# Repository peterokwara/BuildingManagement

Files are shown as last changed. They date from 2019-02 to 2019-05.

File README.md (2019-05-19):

# Table of Contents

- [Table of Contents](#table-of-contents)
- [Building Management System](#building-management-system)
- [Video example](#video-example)
- [Dashboard](#dashboard)
- [Hardware setup](#hardware-setup)
  - [Esp & Current sensor](#esp--current-sensor)
  - [Esp & Dht sensor](#esp--dht-sensor)
  - [Esp & Motion sensor](#esp--motion-sensor)
  - [Esp & Relay](#esp--relay)
- [Installation](#installation)
  - [Esp](#esp)
  - [Raspberry Pi](#raspberry-pi)
  - [Server](#server)
  - [Client](#client)
- [Usage](#usage)
  - [Raspberry Pi](#raspberry-pi-1)
  - [Website (server and client)](#website-server-and-client)
- [Contributing](#contributing)
- [License](#license)

# Building Management System

This project seeks to demonstrate the use of MQTT protocol and MERN stack for building an IoT Building Management System for commercial usage, where parameters such as building occupancy, energy demand, andenergy consumption are measured and displayed on an online database and dashboard.

A more detailed description of the project can be found [here](https://github.com/peterokwara/BuildingManagement/blob/master/Project%20Report.pdf).

# Video example

A video of the project working (hardware)

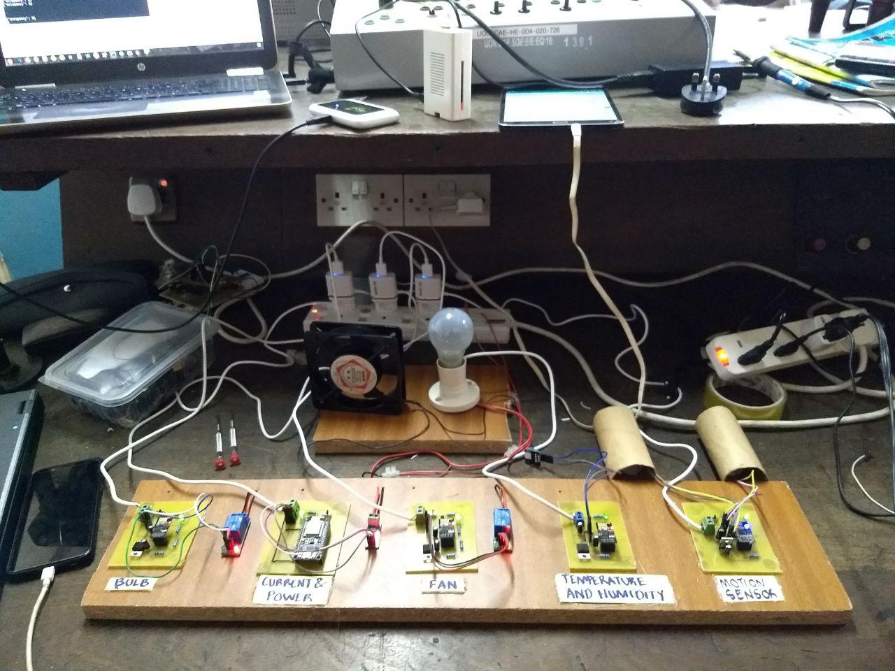
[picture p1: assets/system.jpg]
board setup of the building management system
<a href="https://www.youtube.com/watch?v=Yh3uR8R79lM" target="_blank"></a>

A video of the project working (software)

<a href="https://youtu.be/3eJK0t_gp44
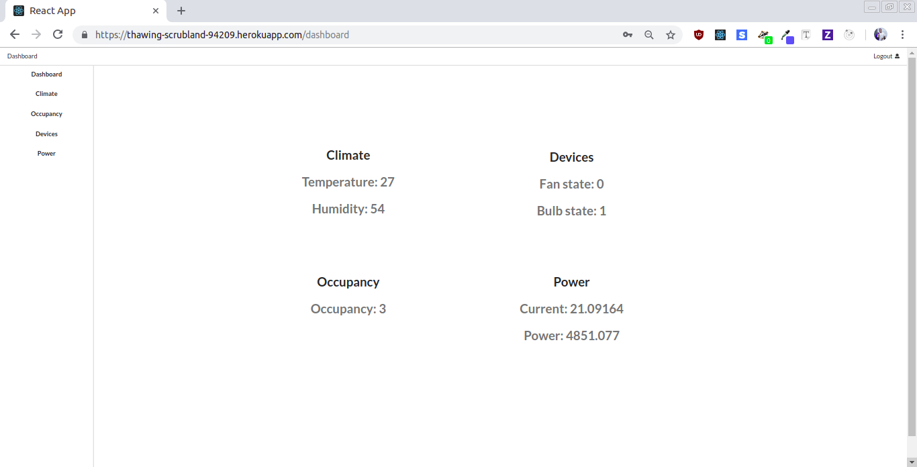
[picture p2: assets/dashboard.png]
video of the dashboard
" target="_blank"></a>

# Dashboard

You can access the dashboard after you sign up [here](https://thawing-scrubland-94209.herokuapp.com/)

# Hardware setup

## Esp & Current sensor

Circuit design

<p  align="center">
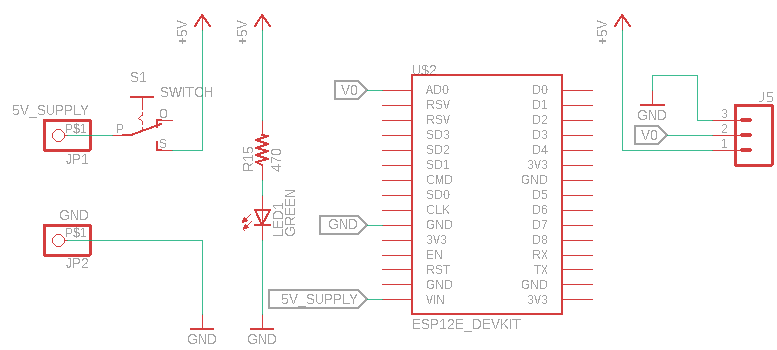
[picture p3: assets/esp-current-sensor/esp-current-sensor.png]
  
</p>

Board design and the final look

<p align="center">
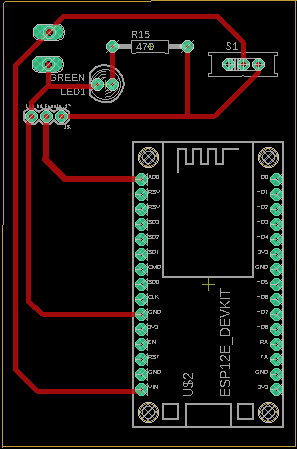
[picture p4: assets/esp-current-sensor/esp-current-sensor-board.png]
  
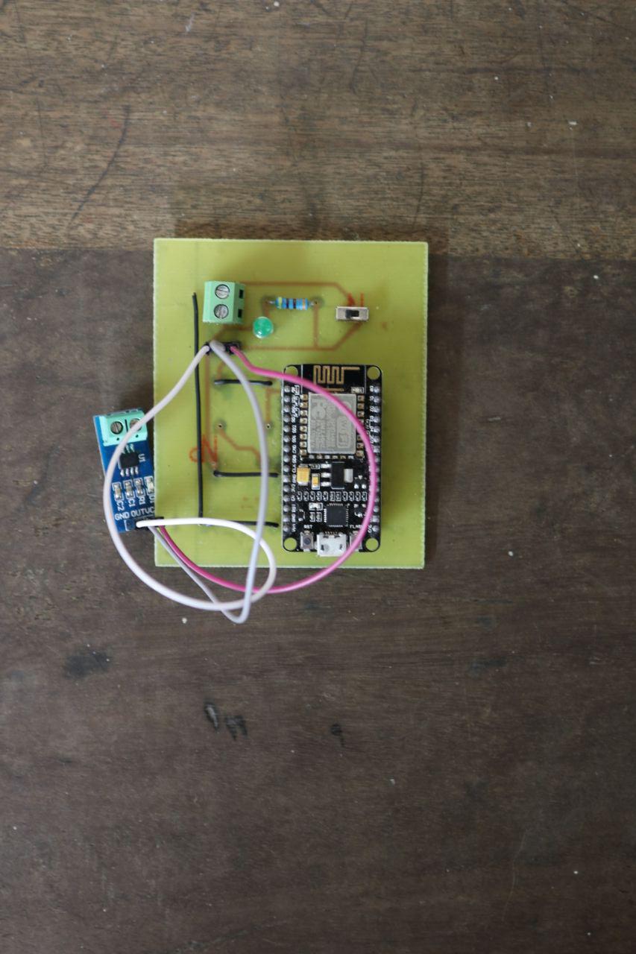
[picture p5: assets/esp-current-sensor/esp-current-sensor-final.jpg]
   
</p>

## Esp & Dht sensor

Circuit design

<p align="center">
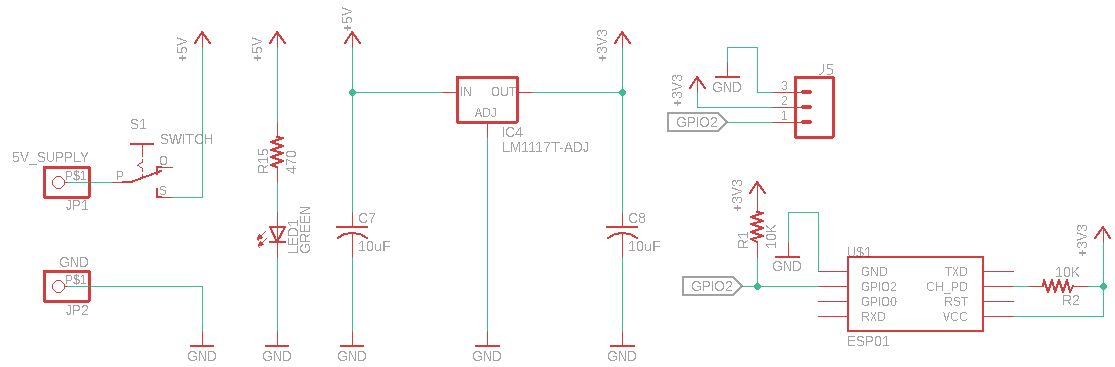
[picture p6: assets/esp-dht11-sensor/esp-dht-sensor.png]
  
</p>

Board design and the final look

<p align="center">
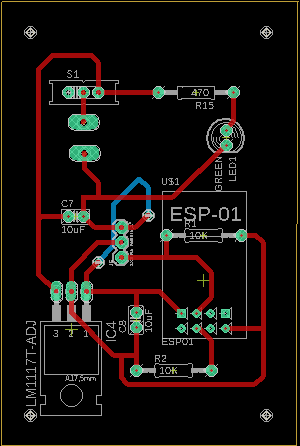
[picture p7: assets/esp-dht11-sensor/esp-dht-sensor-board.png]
  
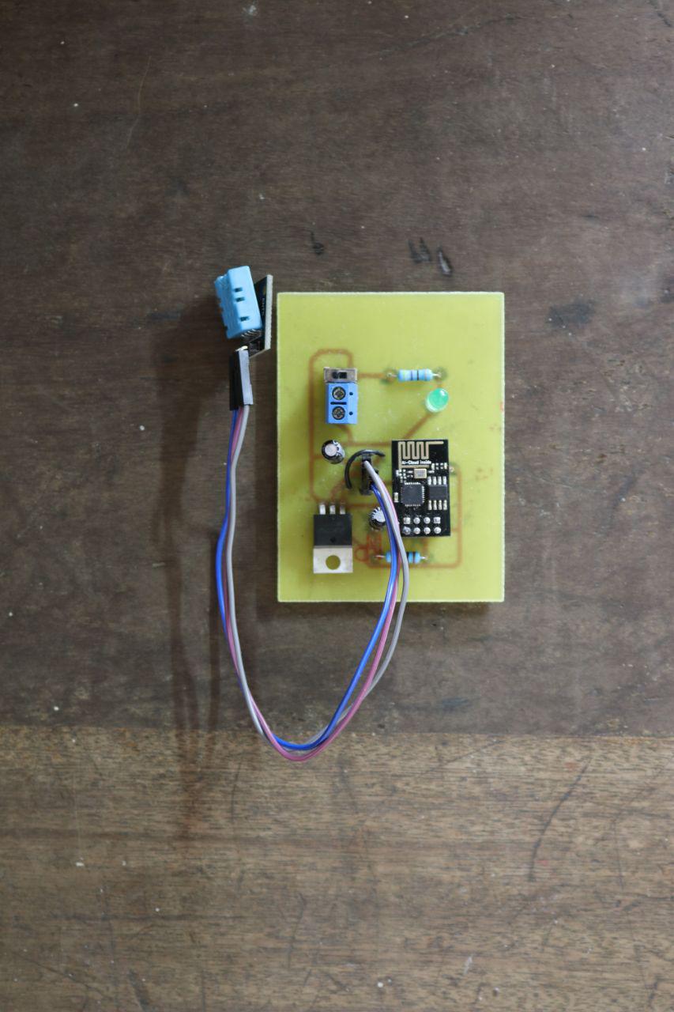
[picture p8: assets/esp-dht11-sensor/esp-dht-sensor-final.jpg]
   
</p>

## Esp & Motion sensor

Circuit design

<p align="center">
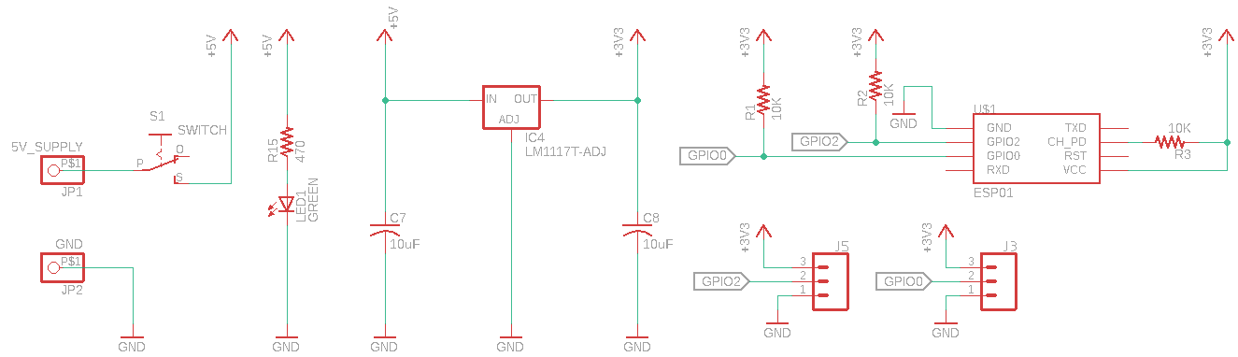
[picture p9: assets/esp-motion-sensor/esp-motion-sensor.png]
  
</p>

Board design and the final look

<p align="center">
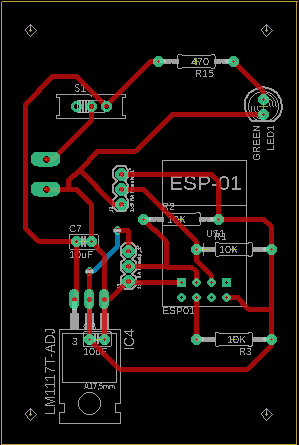
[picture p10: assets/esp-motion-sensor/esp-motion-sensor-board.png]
  
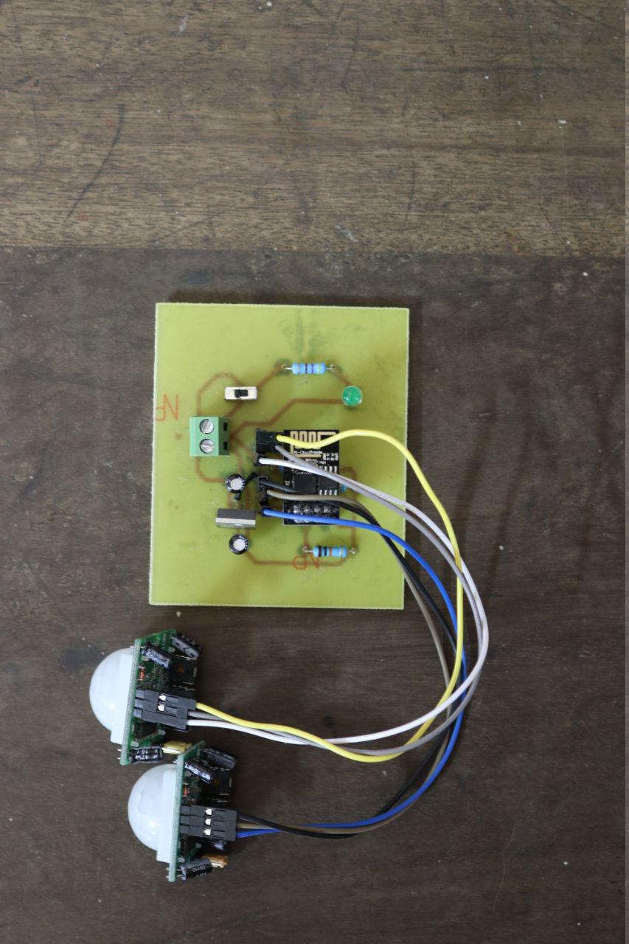
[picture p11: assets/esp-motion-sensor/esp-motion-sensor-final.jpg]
   
</p>

## Esp & Relay

Circuit design

<p align="center">
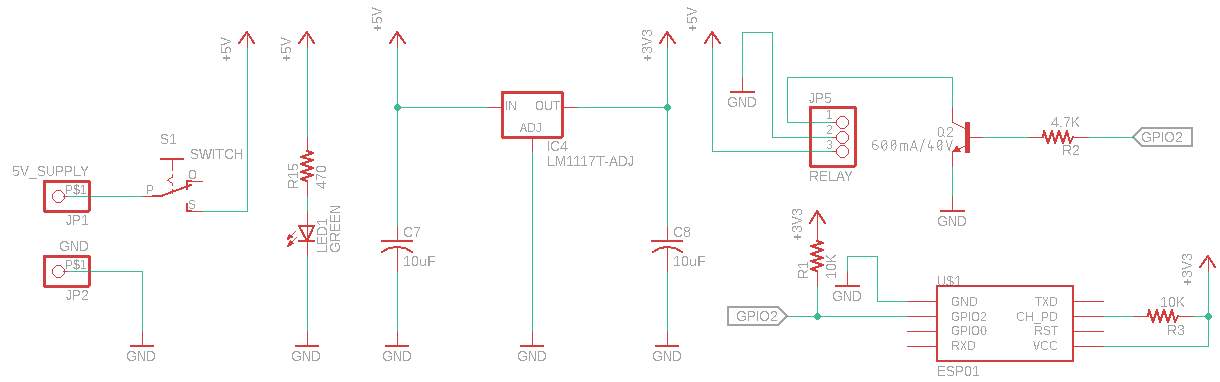
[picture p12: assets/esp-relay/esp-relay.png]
  
</p>

Board design and the final look

<p align="center">
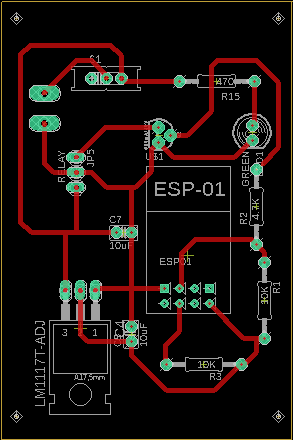
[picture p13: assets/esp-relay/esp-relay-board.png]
  
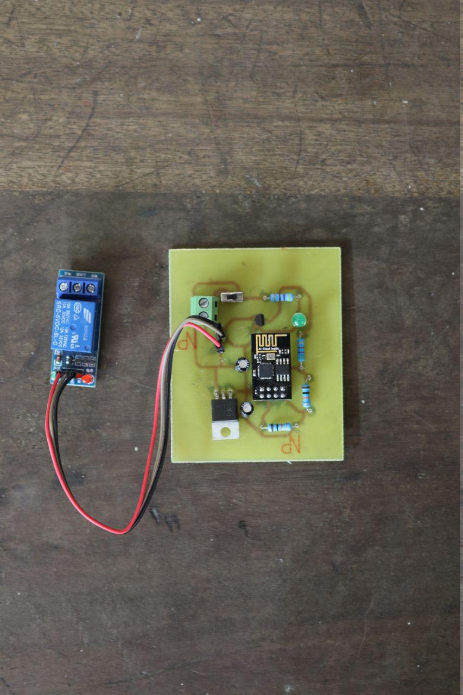
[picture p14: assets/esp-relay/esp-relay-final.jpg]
   
</p>

# Installation

## Esp

Installing in an ESP8266-01 and NodeMCU involves pushing the python files into the device whether it's via a usb to ttl or just a usb cable. This can be done using the command

```bash
sudo ampy --port /dev/ttyUSB0 --baud 115200 put main.py
sudo ampy --port /dev/ttyUSB0 --baud 115200 put config.py
sudo ampy --port /dev/ttyUSB0 --baud 115200 put connectWifi.py
```

You need to create a config.py file with the following information for each and every esp folder (current-sensor, dht-sensor, motion-sensor, relay-bulb, relay-fan)

```python
MQTT_CONFIG = {
    'SENSOR_ID': '',
    'MQTT_HOST': '',
    'PORT': '',
    'PUB_TOPIC': ''
}

WIFI_CONFIG = {
    'WIFI_ESSID': '',
    'WIFI_PASSWORD': ''
}
```

## Raspberry Pi

To install npm packages used for the Raspberry Pi, you run.

```bash
npm install axios mongoose mqtt
```

You also need to create a config folder and have two files that contain config/broker.js

```js
module.exports = {
  brokerUrl: ""
};
```

and config/server.js

```js
module.exports = {
  serverUrl: ""
};
```

## Server

To install npm packages used for the server, you run.

```bash
npm install axios bcryptjs body-parser concurrently cors express gravatar jsonwebtoken mongoose mqtt passport passport-jwt recharts validator
```

You also need to have a config/keys_dev.js with the configuration above. The mongoUri and secretOrKey are obtained when you create a mongodb on https://mlab.com the database I used.

```js
module.exports = {
  mongoUri: "",
  secretOrKey: ""
};
```

## Client

To install npm packages used for the client, you run.

```bash
npm install jwt-decode axios react-redux redux recharts redux-thunk semantic-ui-css semantic-ui-react
```

# Usage

## Raspberry Pi

To run the code for Raspberry Pi just cd into the folder and run

```bash
node app.js
```

To ensure that the Raspberry Pi runs the code whenever it boots, edit the rc.local file

```
sudo nano /etc/rc.local
```

and add

```
node app.js &
```

## Website (server and client)

To run a local development of the website, all you need to do is to do the installation setup then once that is done

```
cd site && npm run dev
```

# Contributing

Pull requests are welcome. For major changes, please open an issue first to discuss what you would like to change.

Please make sure to update tests as appropriate.

# License

[MIT](https://github.com/peterokwara/BuildingManagement/blob/master/LICENSE)

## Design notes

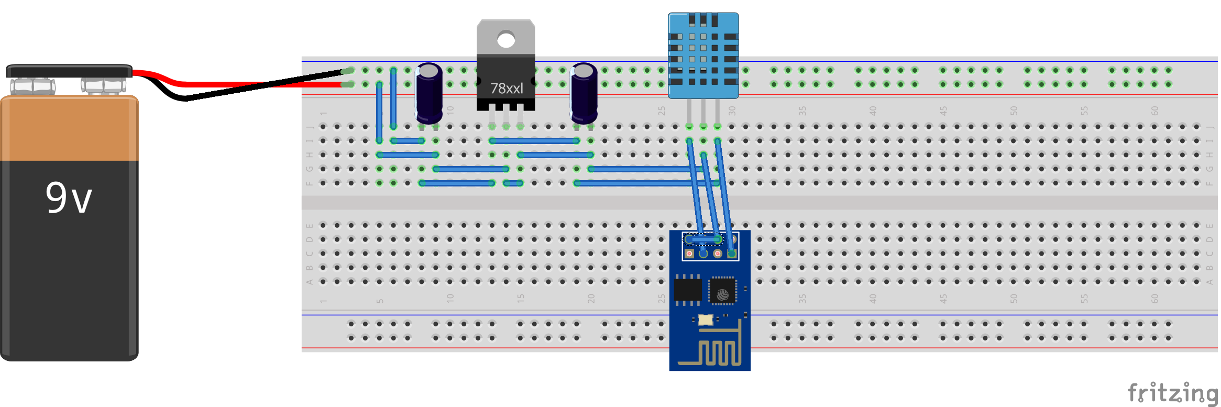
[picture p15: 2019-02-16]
schematics/Fritzing/esp_and_temp_sensor/esp_temp_sensor_bb.png

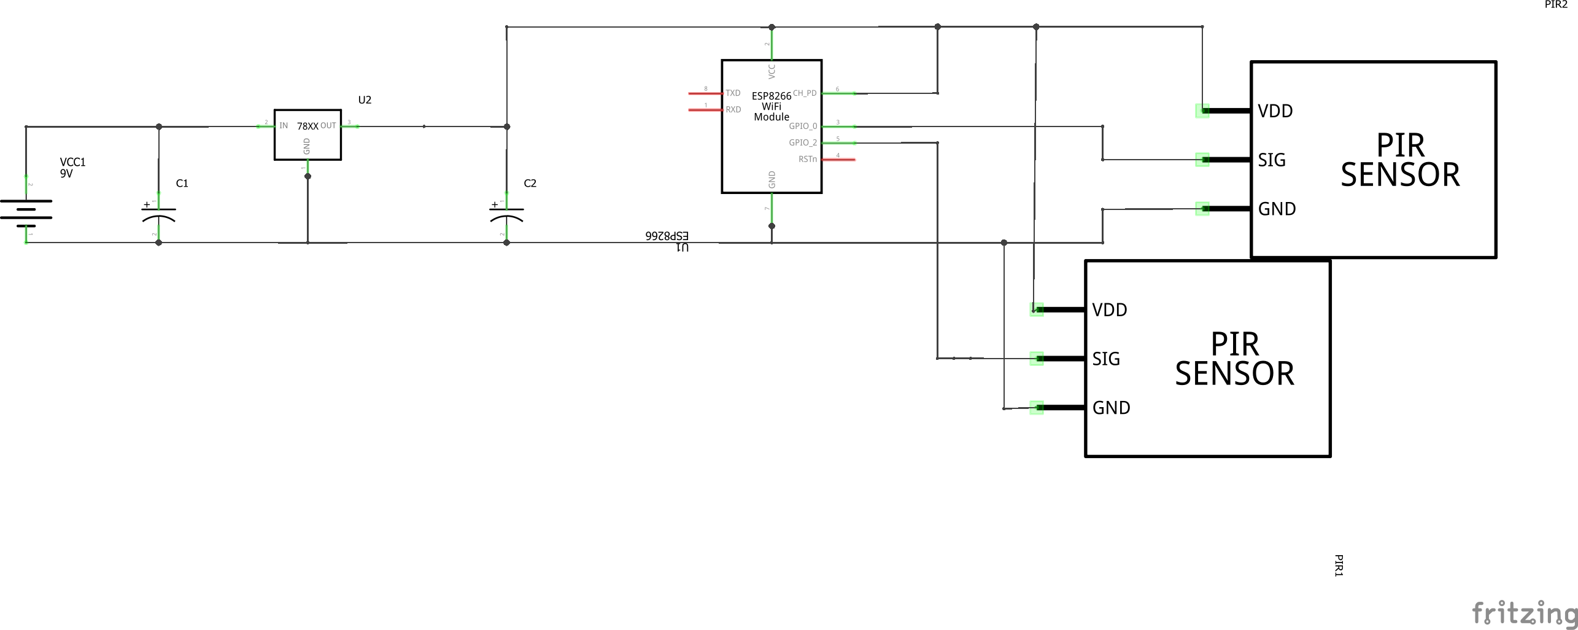
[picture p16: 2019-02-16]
schematics/Fritzing/esp_and_motion_sensor/esp_motion_sensor_schem.png

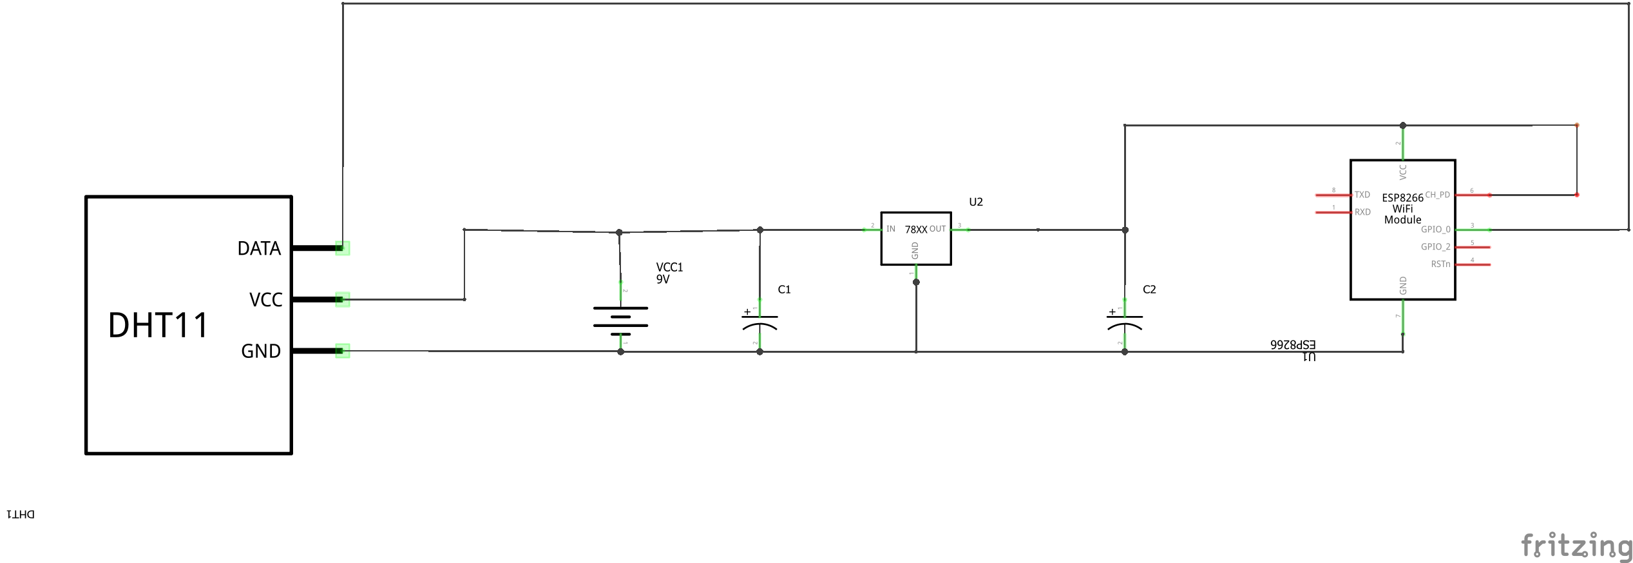
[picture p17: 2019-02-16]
schematics/Fritzing/esp_and_temp_sensor/esp_temp_sensor_schem.png

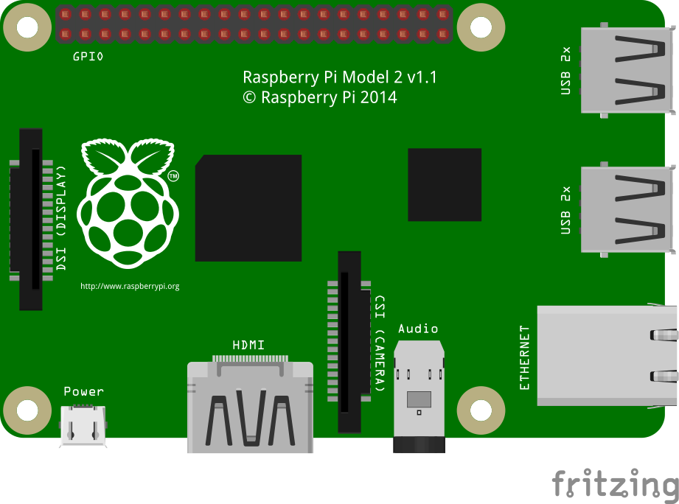
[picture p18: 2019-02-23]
schematics/Fritzing/raspberry_pi/raspberry_pi_bb.png

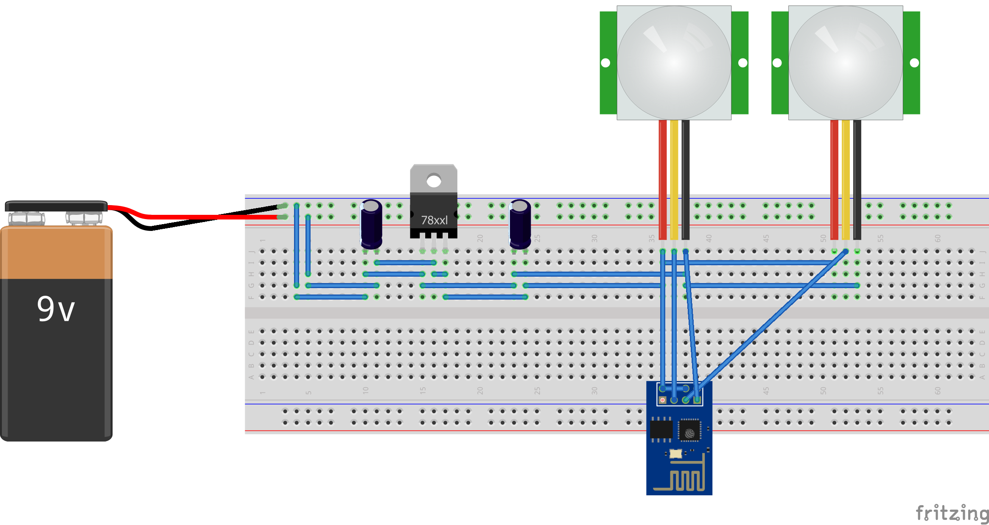
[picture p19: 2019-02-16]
schematics/Fritzing/esp_and_motion_sensor/esp_motion_sensor_bb.png

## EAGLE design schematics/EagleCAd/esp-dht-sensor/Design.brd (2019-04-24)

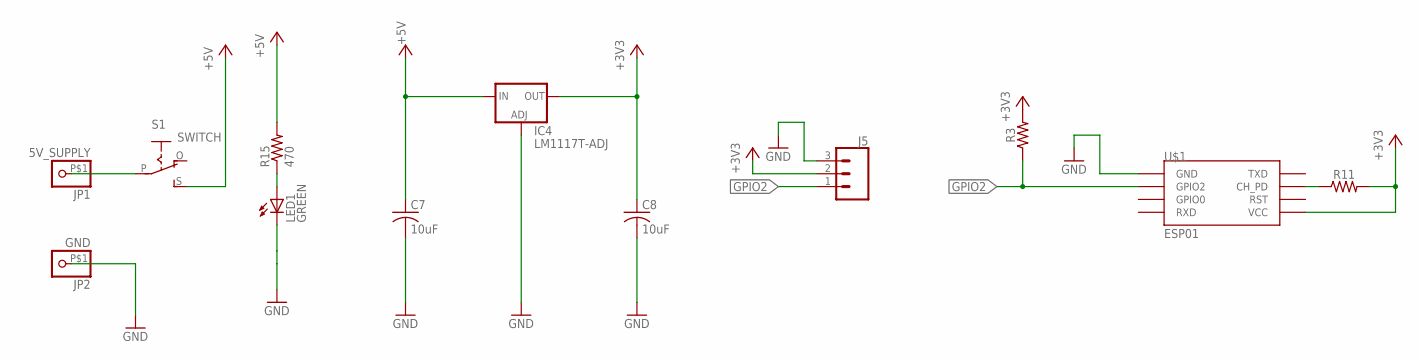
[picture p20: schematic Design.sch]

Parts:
C7, C8: 10uF; C025-025X050
IC4: LM1117T-ADJ; TO220
J5: 1x3 RA Female .1"; 1X03
JP1: 5V_SUPPLY; 1X1-BIGPOGO
JP2: GND; 1X1-BIGPOGO
LED1: GREEN; LED5MM
R3, R11: 10k; 0207/12
R15: 470; 0207/12
S1: SWITCH; EG1218
U$1: ESP01

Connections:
+3V3: C8.1, IC4.2 (OUT), J5.2, R3.2, R11.2, U$1.VCC
+5V: C7.1, IC4.3 (IN), R15.2, S1.S
GND: C7.2, C8.2, IC4.1 (ADJ), J5.3, JP2.P$1, LED1.K (C), U$1.GND
GPIO2: J5.1, R3.1, U$1.GPIO2
unnamed: JP1.P$1, S1.P
unnamed: R11.1, U$1.CH_PD
unnamed: LED1.A, R15.1

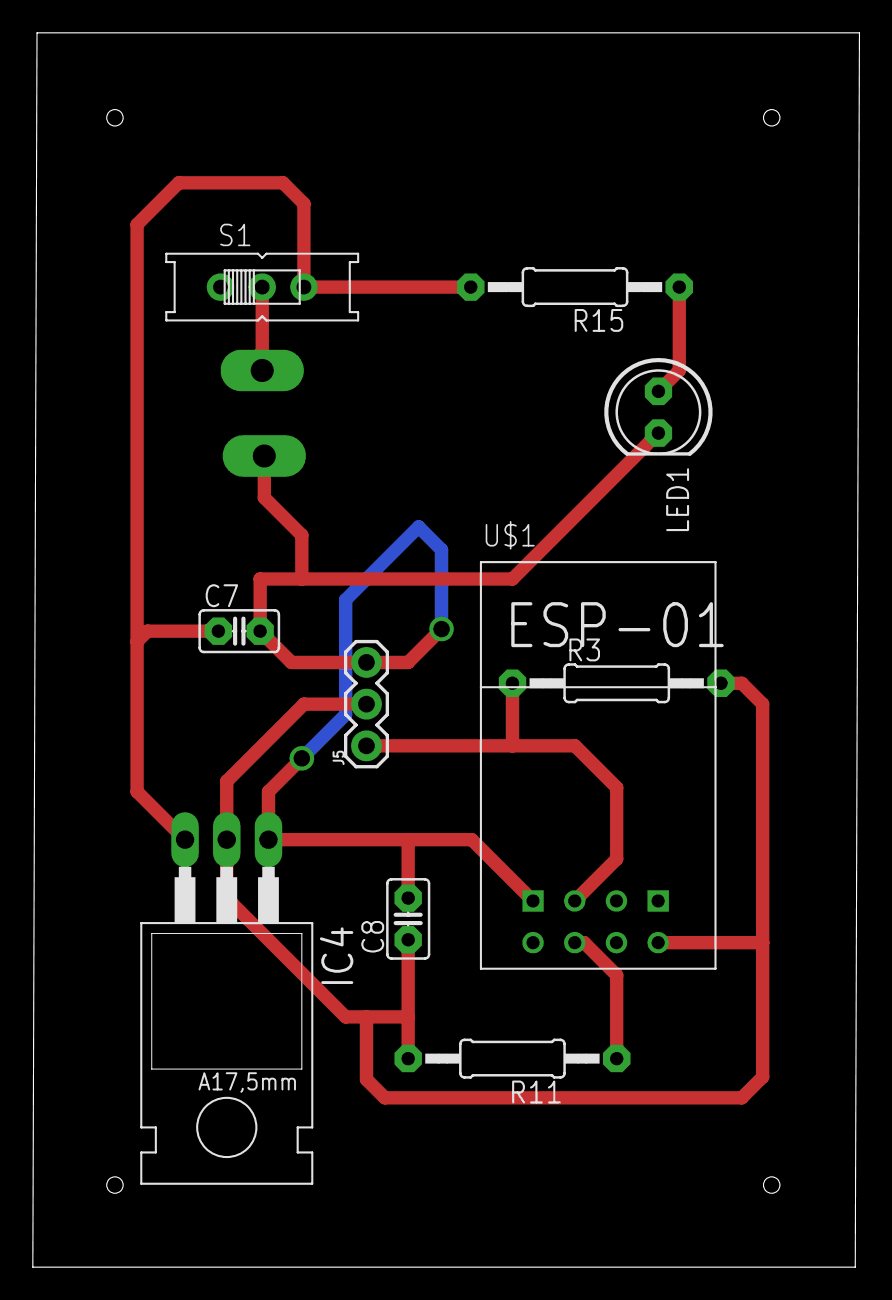
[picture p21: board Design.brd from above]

Board: 2 copper layers, 50.3 x 75.2 mm, 12 parts (0 on the bottom side), 7 nets.

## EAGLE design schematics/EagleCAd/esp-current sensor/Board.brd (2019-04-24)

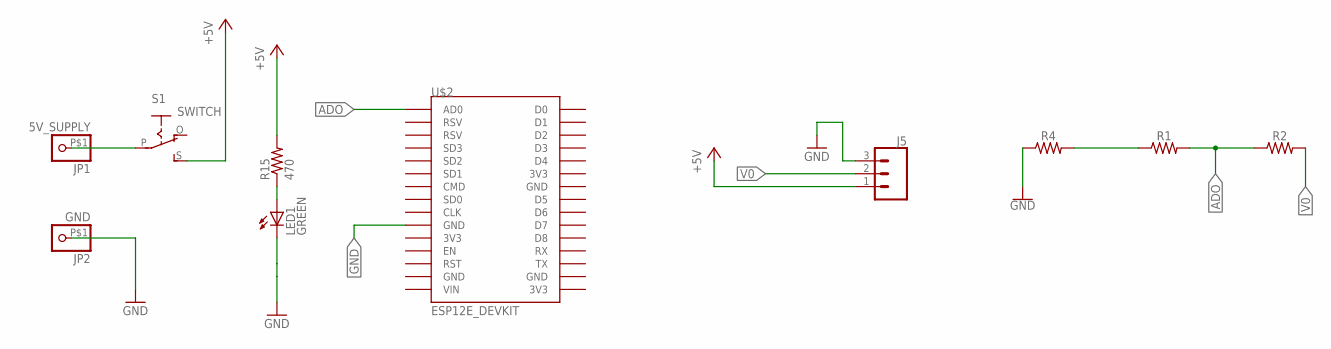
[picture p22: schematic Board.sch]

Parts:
J5: 1x3 RA Female .1"; 1X03
JP1: 5V_SUPPLY; 1X1-BIGPOGO
JP2: GND; 1X1-BIGPOGO
LED1: GREEN; LED5MM
R1: 101; 0207/12
R2: 10k; 0207/12
R4: 2.4k; 0207/12
R15: 470; 0207/12
S1: SWITCH; EG1218
U$2: ESP12E_DEVKIT

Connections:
+5V: J5.1, R15.2, S1.S
ADO: R1.2, R2.1, U$2.AD0
GND: J5.3, JP2.P$1, LED1.K (C), R4.1, U$2.GND@0 (GND)
unnamed: R1.1, R4.2
unnamed: JP1.P$1, S1.P
unnamed: LED1.A, R15.1
V0: J5.2, R2.2

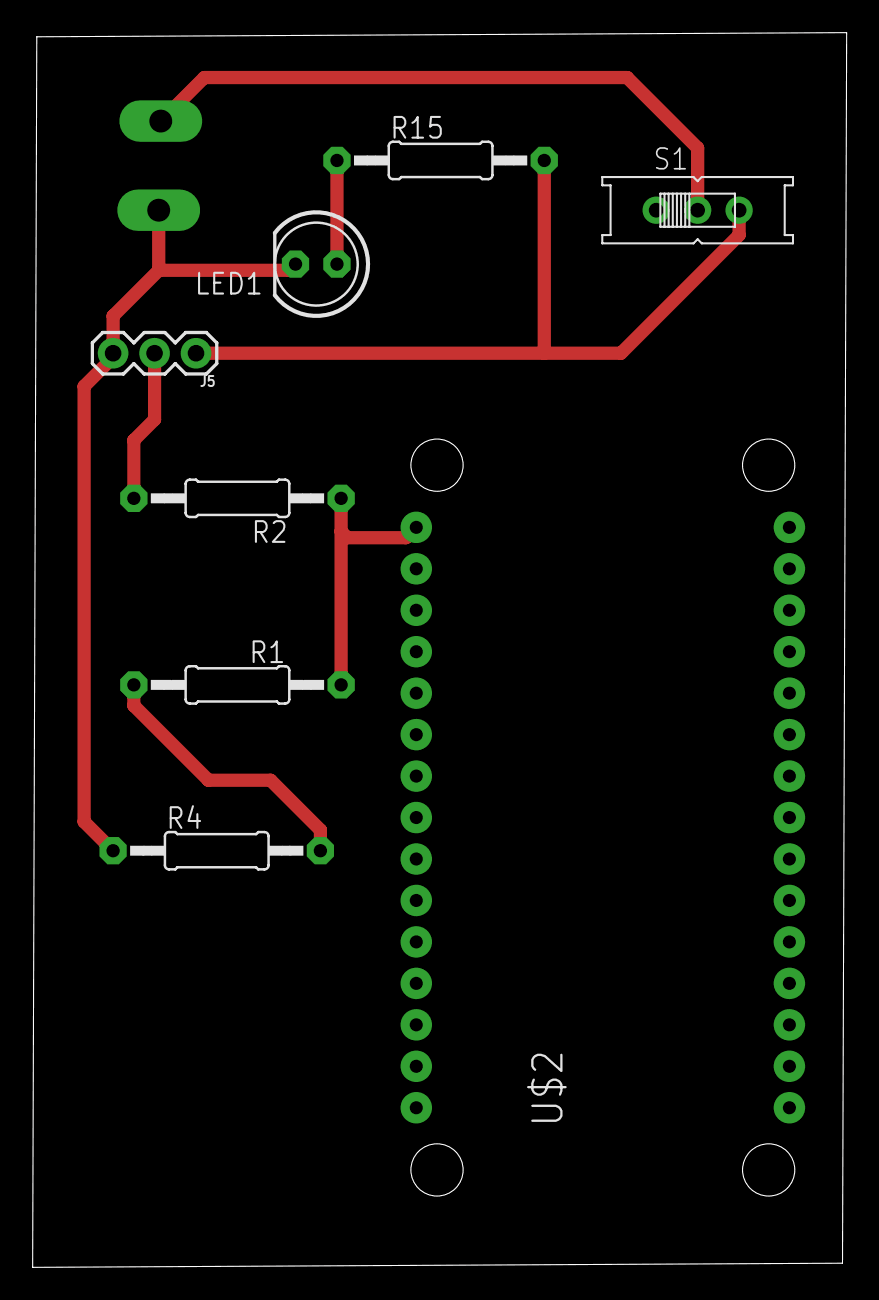
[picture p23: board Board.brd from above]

Board: 2 copper layers, 49.9 x 75.6 mm, 10 parts (0 on the bottom side), 7 nets.

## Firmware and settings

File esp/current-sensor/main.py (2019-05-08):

# Peter Okwara
# F17/36211/2013 

# This piece of code collects analog values for current from the ACS712 5A current sensor 
# and provides the current and power consumed by devices connected to the current sensor

import connectWifi
import time
import config
import json
import time
import utime
import machine
import math
from umqtt.simple import MQTTClient

connectWifi.connect()
ADC_SCALE = 1023.0
VREF = 5.0
sensitivity = 0.185
U = 230
adc = machine.ADC(0)

SERVER = config.MQTT_CONFIG['MQTT_HOST']
PORT = config.MQTT_CONFIG['PORT']
SENSOR_ID = config.MQTT_CONFIG['SENSOR_ID']
PUB_TOPIC = config.MQTT_CONFIG['PUB_TOPIC']

# function for callibrating the current sensor
def calibrate():
    global zero
    acc = 0
    x = 0
    while x < 10:
        acc += adc.read()
        x = x + 1
    zero = acc / 10
    return zero

# function for getting the current and power value from sensor
def read_sensor():
    frequency = 50
    period = 1000000 / frequency
    Isum = 0
    measurements_count = 0
    t_start = utime.ticks_ms()

    while (utime.ticks_ms() - t_start < period):
        Inow = adc.read() - zero
        Isum += Inow*Inow
        measurements_count = measurements_count + 1

    Irms = math.sqrt(Isum/measurements_count) / ADC_SCALE * VREF / sensitivity

    P = U * Irms
    return {
        "current": Irms,
        "power": P
    }

# function for sending data to the MQTT broker
def send(data):
    c = MQTTClient(SENSOR_ID, SERVER, 1883)
    c.connect()
    c.publish(PUB_TOPIC, data)
    c.disconnect()


def main():
    # start by callibrating the sensor
    calibrate()
    while True:
        # read the analog value from the sensor
        data = read_sensor()
        # transmit the analog value via MQTT
        send(data)


if __name__ == "__main__":
    main()

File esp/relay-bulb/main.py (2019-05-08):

#Peter Okwara
# F17/36211/2013 

# This piece of code awaits for instructions to turn on or off a GPIO pin to control a relay

import connectWifi
import time
import config
import json
from dht import DHT11
from machine import Pin
from umqtt.simple import MQTTClient

# connect to wifi
connectWifi.connect()

# set GPIO_2 pin as an output pin
RPin = Pin(2, Pin.OUT, value=0)

SERVER = config.MQTT_CONFIG['MQTT_HOST']
PORT = config.MQTT_CONFIG['PORT']
SENSOR_ID = config.MQTT_CONFIG['SENSOR_ID']
PUB_TOPIC = config.MQTT_CONFIG['PUB_TOPIC']

c = MQTTClient(SENSOR_ID, SERVER)

# function to set relay on
def relay_on():
    send("Relay on")
    RPin.on()

# function to set relay off
def relay_off():
    send("Relay off")
    RPin.off()

# function to send confirmation that relay is on or off
def send(data):
    c.publish(PUB_TOPIC, json.dumps(data))

# function to subscribe for incomimg commands
def sub_cb(topic, msg):
    print((topic, msg))
    command = msg.decode('ASCII')
    if command == "on":
        relay_on()
    elif command == "off":
        relay_off()


def main(server=SERVER):
    c.set_callback(sub_cb)
    c.connect()
    c.subscribe(PUB_TOPIC)
    # check for incoming messages/commands
    while True:
        if True:
            # Blocking wait for message
            c.wait_msg()
        else:
            # Non-blocking wait for message
            c.check_msg()
            # Then need to sleep to avoid 100% CPU usage (in a real
            # app other useful actions would be performed instead)
            time.sleep(1)

    c.disconnect()


if __name__ == "__main__":
    main()

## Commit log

2019-01-27 Add code to connect to wifi and read from gpio pin
2019-01-30 Pir sensor 1 sending data to raspi
2019-01-30 Update two code to work for both pir sensors
2019-02-01 Add schematics for the PIR motion sensor and esp
    [pir-sensors-with-esp.sch]
2019-02-06 Print message whether user authenticated successfully or not
2019-02-09 Get the user flow
2019-02-10 Create route for saving pir sensor data
2019-02-10 Add code for sending pir motion sensor data
2019-02-10 Change publish data from pir sensor
2019-02-10 Create table for motion sensor data
2019-02-10 Add route to get all motion sensor data
2019-02-10 Add devices reducer
2019-02-16 Add schematic files from fritzing software
    [esp_motion_sensor.fzz, esp_temp_sensor.fzz]
2019-02-16 Upload better breadboard schematic
2019-02-16 Upload changes to bread board schematic
2019-02-19 Add simple code to get temperature data from dht11
2019-02-19 Send humidity and temperature data to raspberry pi
2019-02-20 Remove former temperature files
2019-02-20 Send both temperature and humidity data
2019-02-20 Create routes for the dht sensor
2019-02-20 Add code to fetch temperature data and render it on a table
2019-02-20 Remove temperature components
2019-02-21 Add line chart component to display temperature and humidity values
2019-02-23 Add raspberry pi photo
    [raspberry_pi.fzz]
2019-04-18 Add etching files for all circuits
    [Board.brd, Board.sch, Design.brd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]
2019-04-24 Add eagle file and fritzing file separately
    [Board.brd, Board.sch, Design.brd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]
2019-04-25 Enable storage and retrieval of power consumption data
2019-04-25 Enable one to store and fetch data on devices
2019-04-25 Add power component and fetch data power
2019-04-25 Change line chart component to accept props instead of hard coded values
2019-04-25 Add props that are sent to the dht sensor component
2019-04-25 Show data on devices state
2019-04-26 Add dashboard showing all the current information
2019-04-26 Add relevant legend title for x_axis and y_axis
2019-04-27 Add code for the raspberry pi node js file
2019-04-29 Send data with one pir motion sensor
2019-04-30 New code for the motion sensors
2019-05-04 Tun on fan if temperature is above 30 degrees and turn off fan if temperature is below
2019-05-05 Use interrupts to capture motion
2019-05-05 Add measure and delay missing from code
    [main.py]

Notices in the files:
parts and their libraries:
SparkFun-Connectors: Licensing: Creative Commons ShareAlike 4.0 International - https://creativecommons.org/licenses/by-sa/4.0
